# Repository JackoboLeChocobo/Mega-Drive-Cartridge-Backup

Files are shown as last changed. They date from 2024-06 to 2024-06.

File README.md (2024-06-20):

# Mega Drive Cartridge Backup

Fork du projet de X-Death25, auteur originel du projet : https://github.com/X-death25/MD-Dumper

Merci à lui pour les informations sur son projet et pour son aide sur l'utlisation du STM32F401CCU6.

## Objectifs

- Pouvoir récupérer les données de ses propres cartouches Mega Drive

## Outils utilisés

- Système d'exploitation : Debian 12 / Fenikkusu ( Linux )
- Carte de développement STM32F401CCU6 + 3x 74LS273

## Statut du projet 

En attente :

- Réalisation de la carte / Soudure

Etapes Validés :
- Schéma / Typon Kicad réalisés
- Firmware / Logiciel recompilables avec les outils open-source
- Programmeur du STM32F401CCU6 recompilable avec les outils open-source
- Détection du STM32F401CCU6 en tant que "Mega Drive Dumper" sous Linux avec dmesg et le logiciel d'utilisation
- Composants 74LS273 reçus

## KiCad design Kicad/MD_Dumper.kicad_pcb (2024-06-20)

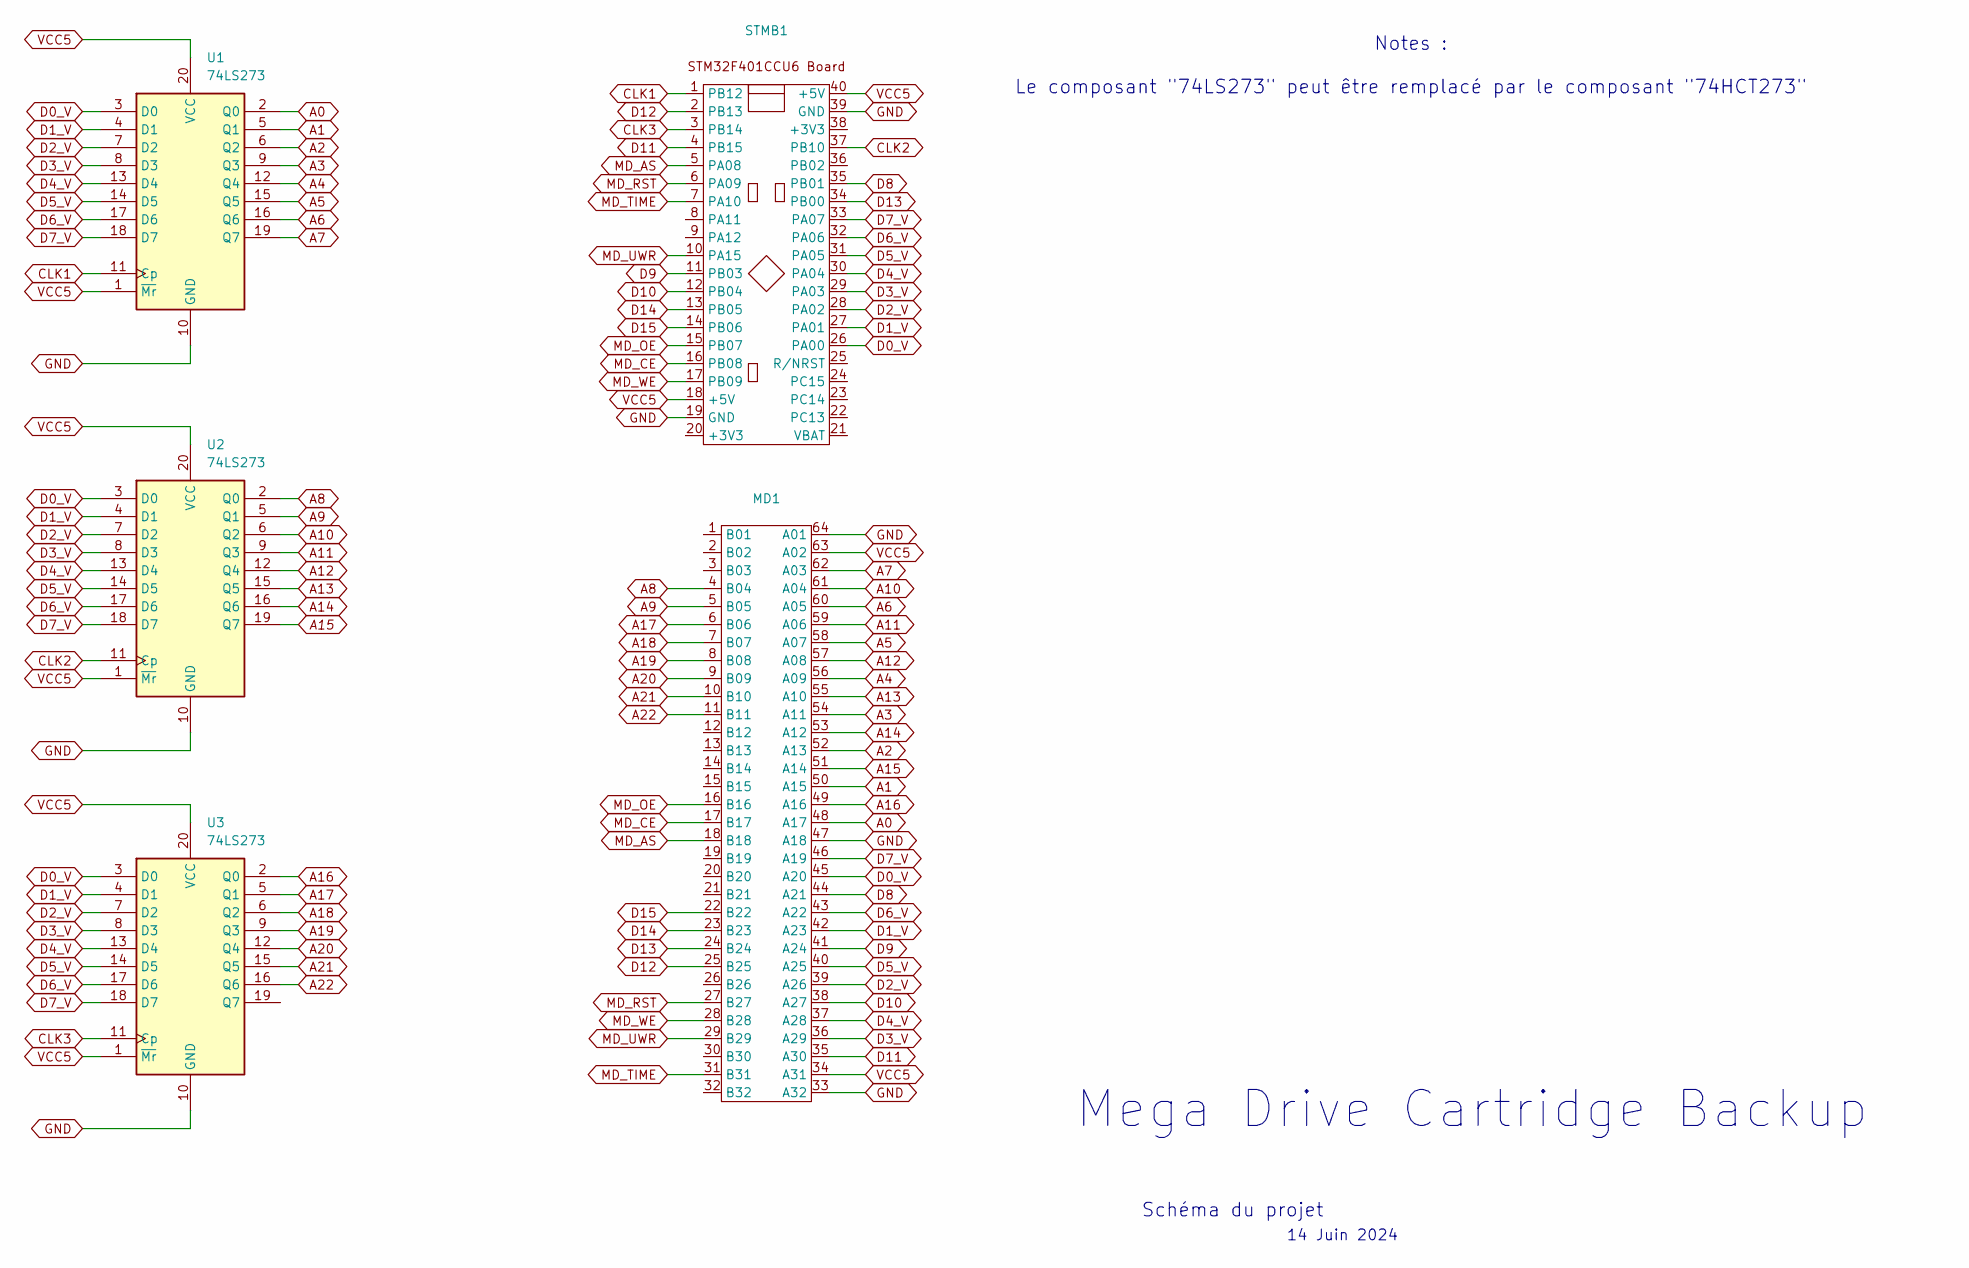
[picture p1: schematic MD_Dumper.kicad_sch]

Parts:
MD1: Conn_MD
STMB1: STM32F401CCU6 Board
U1, U2, U3: 74LS273; DIP-20_W7.62mm

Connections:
A0: MD1.48 (A17), U1.2 (Q0)
A1: MD1.50 (A15), U1.5 (Q1)
A2: MD1.52 (A13), U1.6 (Q2)
A3: MD1.54 (A11), U1.9 (Q3)
A4: MD1.56 (A09), U1.12 (Q4)
A5: MD1.58 (A07), U1.15 (Q5)
A6: MD1.60 (A05), U1.16 (Q6)
A7: MD1.62 (A03), U1.19 (Q7)
A8: MD1.4 (B04), U2.2 (Q0)
A9: MD1.5 (B05), U2.5 (Q1)
A10: MD1.61 (A04), U2.6 (Q2)
A11: MD1.59 (A06), U2.9 (Q3)
A12: MD1.57 (A08), U2.12 (Q4)
A13: MD1.55 (A10), U2.15 (Q5)
A14: MD1.53 (A12), U2.16 (Q6)
A15: MD1.51 (A14), U2.19 (Q7)
A16: MD1.49 (A16), U3.2 (Q0)
A17: MD1.6 (B06), U3.5 (Q1)
A18: MD1.7 (B07), U3.6 (Q2)
A19: MD1.8 (B08), U3.9 (Q3)
A20: MD1.9 (B09), U3.12 (Q4)
A21: MD1.10 (B10), U3.15 (Q5)
A22: MD1.11 (B11), U3.16 (Q6)
CLK1: STMB1.1 (PB12), U1.11 (Cp)
CLK2: STMB1.37 (PB10), U2.11 (Cp)
CLK3: STMB1.3 (PB14), U3.11 (Cp)
D0_V: MD1.45 (A20), STMB1.26 (PA00), U1.3 (D0), U2.3 (D0), U3.3 (D0)
D1_V: MD1.42 (A23), STMB1.27 (PA01), U1.4 (D1), U2.4 (D1), U3.4 (D1)
D2_V: MD1.39 (A26), STMB1.28 (PA02), U1.7 (D2), U2.7 (D2), U3.7 (D2)
D3_V: MD1.36 (A29), STMB1.29 (PA03), U1.8 (D3), U2.8 (D3), U3.8 (D3)
D4_V: MD1.37 (A28), STMB1.30 (PA04), U1.13 (D4), U2.13 (D4), U3.13 (D4)
D5_V: MD1.40 (A25), STMB1.31 (PA05), U1.14 (D5), U2.14 (D5), U3.14 (D5)
D6_V: MD1.43 (A22), STMB1.32 (PA06), U1.17 (D6), U2.17 (D6), U3.17 (D6)
D7_V: MD1.46 (A19), STMB1.33 (PA07), U1.18 (D7), U2.18 (D7), U3.18 (D7)
D8: MD1.44 (A21), STMB1.35 (PB01)
D9: MD1.41 (A24), STMB1.11 (PB03)
D10: MD1.38 (A27), STMB1.12 (PB04)
D11: MD1.35 (A30), STMB1.4 (PB15)
D12: MD1.25 (B25), STMB1.2 (PB13)
D13: MD1.24 (B24), STMB1.34 (PB00)
D14: MD1.23 (B23), STMB1.13 (PB05)
D15: MD1.22 (B22), STMB1.14 (PB06)
GND: MD1.33 (A32), MD1.47 (A18), MD1.64 (A01), STMB1.19 (GND), STMB1.39 (GND), U1.10 (GND), U2.10 (GND), U3.10 (GND)
MD_AS: MD1.18 (B18), STMB1.5 (PA08)
MD_CE: MD1.17 (B17), STMB1.16 (PB08)
MD_OE: MD1.16 (B16), STMB1.15 (PB07)
MD_RST: MD1.27 (B27), STMB1.6 (PA09)
MD_TIME: MD1.31 (B31), STMB1.7 (PA10)
MD_UWR: MD1.29 (B29), STMB1.10 (PA15)
MD_WE: MD1.28 (B28), STMB1.17 (PB09)
VCC5: MD1.34 (A31), MD1.63 (A02), STMB1.18 (+5V), STMB1.40 (+5V), U1.1 (~Mr), U1.20 (VCC), U2.1 (~Mr), U2.20 (VCC), U3.1 (~Mr), U3.20 (VCC)

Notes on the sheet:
Mega Drive Cartridge Backup
Notes : Le composant "74LS273" peut être remplacé par le composant "74HCT273"
14 Juin 2024
Schéma du projet

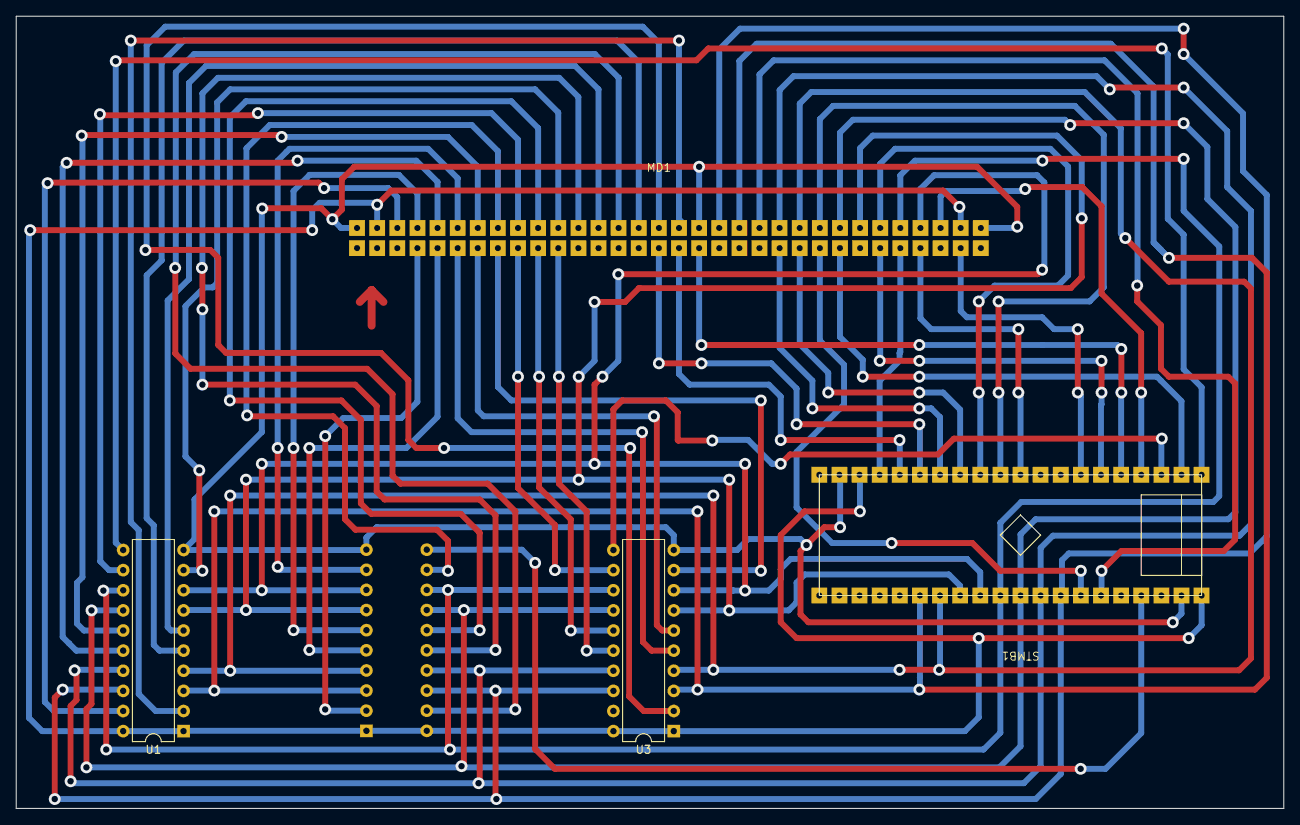
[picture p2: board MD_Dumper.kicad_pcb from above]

Board: 2 copper layers, 160.0 x 100.0 mm, 5 parts (1 on the bottom side), 51 nets.

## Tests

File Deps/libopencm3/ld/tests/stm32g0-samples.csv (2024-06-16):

# manually ripped from
# https://www.st.com/en/microcontrollers-microprocessors/stm32g0x0-value-line.html
# on 2024-01-17
name | flash | ram
stm32g030j6 | 32k | 8k
stm32g030f6 | 32k | 8k
stm32g030k6 | 32k | 8k
stm32g030c6 | 32k | 8k
stm32g050f6 | 32k | 18k
stm32g050k6 | 32k | 18k
stm32g050c6 | 32k | 18k
stm32g030k8 | 64k | 8k
stm32g030c8 | 64k | 8k
stm32g050k8 | 64k | 18k
stm32g050c8 | 64k | 18k
stm32g070kb | 128k | 36k
stm32g070cb | 128k | 36k
stm32g070rb | 128k | 36k
stm32g0b0ke | 512k | 144k
stm32g0b0ce | 512k | 144k
stm32g0b0re | 512k | 144k
stm32g0b0ve | 512k | 144k
# Ripped from https://www.st.com/en/microcontrollers-microprocessors/stm32g0x1.html
# on 2024-01-17
stm32g031j4 | 16k | 8k
stm32g031j6 | 32k | 8k
stm32g041j6 | 32k | 8k
stm32g031f4 | 16k | 8k
stm32g031f6 | 32k | 8k
stm32g041f6 | 32k | 8k
stm32g031g4 | 16k | 8k
stm32g031g6 | 32k | 8k
stm32g041g6 | 32k | 8k
stm32g031k4 | 16k | 8k
stm32g031k6 | 32k | 8k
stm32g041k6 | 32k | 8k
stm32g031c4 | 16k | 8k
stm32g031c6 | 32k | 8k
stm32g041c6 | 32k | 8k
stm32g051f6 | 32k | 18k
stm32g061f6 | 32k | 18k
stm32g051g6 | 32k | 18k
stm32g061g6 | 32k | 18k
stm32g051k6 | 32k | 18k
stm32g061k6 | 32k | 18k
stm32g051c6 | 32k | 18k
stm32g061c6 | 32k | 18k
stm32g031f8 | 64k | 8k
stm32g041f8 | 64k | 8k
stm32g051f8 | 64k | 18k
stm32g061f8 | 64k | 18k
stm32g031g8 | 64k | 8k
stm32g041g8 | 64k | 8k
stm32g051g8 | 64k | 18k
stm32g061g8 | 64k | 18k
stm32g031k8 | 64k | 8k
stm32g041k8 | 64k | 8k
stm32g051k8 | 64k | 18k
stm32g061k8 | 64k | 18k
stm32g031c8 | 64k | 8k
stm32g041c8 | 64k | 8k
stm32g051c8 | 64k | 18k
stm32g061c8 | 64k | 18k
stm32g031y8 | 64k | 8k
stm32g041y8 | 64k | 8k
stm32g051y8 | 64k | 18k
stm32g061y8 | 64k | 18k
stm32g071g8 | 64k | 36k
stm32g071k8 | 64k | 36k
stm32g071c8 | 64k | 36k
stm32g071r8 | 64k | 36k
stm32g071gb | 128k | 36k
stm32g081gb | 128k | 36k
stm32g071kb | 128k | 36k
stm32g081kb | 128k | 36k
stm32g071cb | 128k | 36k
stm32g081cb | 128k | 36k
stm32g071rb | 128k | 36k
stm32g081rb | 128k | 36k
stm32g071eb | 128k | 36k
stm32g081eb | 128k | 36k
stm32g0b1kb | 128k | 144k
stm32g0b1kc | 256k | 144k
stm32g0c1kc | 256k | 144k
stm32g0b1cb | 128k | 144k
stm32g0b1cc | 256k | 144k
stm32g0c1cc | 256k | 144k
stm32g0b1rb | 128k | 144k
stm32g0b1rc | 256k | 144k
stm32g0c1rc | 256k | 144k
stm32g0b1mb | 128k | 144k
stm32g0b1mc | 256k | 144k
stm32g0c1mc | 256k | 144k
stm32g0b1vb | 128k | 144k
stm32g0b1vc | 256k | 144k
stm32g0c1vc | 256k | 144k
stm32g0b1ke | 512k | 144k
stm32g0c1ke | 512k | 144k
stm32g0b1ce | 512k | 144k
stm32g0c1ce | 512k | 144k
stm32g0b1re | 512k | 144k
stm32g0c1re | 512k | 144k
stm32g0b1me | 512k | 144k
stm32g0c1me | 512k | 144k
stm32g0b1ve | 512k | 144k
stm32g0c1ve | 512k | 144k
stm32g0b1ne | 512k | 144k
stm32g0c1ne | 512k | 144k

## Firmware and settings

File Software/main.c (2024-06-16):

/*
MD Dumper Software

------------------------------------------------------
* Modifications by Jackobo Le Chocobo - 06/2024
* 
* Objective : Save Cartridge Datas to PC only
* 
* - Removed Write/Flash Cartridge Methods
* - Removed DMC Support
* 
*  
* Original author : X-death - V 2.0 03/2022
* - Upated Flash algo R/W
* - Add Extra Hardware Game Detection
* - Add Sega Lock-ON support
* - Add SSFII classic support
* - Add Pier Solar Support (only dump ROM )
* - Preliminary DMC support
------------------------------------------------------

*/

#include <stdio.h>
#include <stdlib.h>
#include <stdarg.h>
#include <string.h>
#include <ctype.h>
#include <time.h>
#include <math.h>

#include <libusb.h>
#include <assert.h>

#include "s2k.h"

// USB Special Command
#define WAKEUP          0x10  // WakeUP for first STM32 Communication
#define READ_MD         0x11
#define READ_MD_SAVE    0x12
#define READ_SMS   		0x16
#define INFOS_ID        0x18
#define DEBUG_MODE      0x19
#define MAPPER_SSF2     0x20
#define MAPPER_PS   	0x30
#define UNLOCK_PS     	0x31
#define SAVE_BUFFER    	0x41
#define SEND_BUFFER    	0x42
#define WRITE_LOCK_ON  	0x45

// Version
#define MAX_VERSION 	2
#define MIN_VERSION 	0

// Sega Dumper Specific Variable

char * game_rom = NULL;
char * game_name = NULL;
const char unk[] = {"unknown"};
const char * save_msg[] = {	"WRITE SMD save",  //0
                            "ERASE SMD save"
                          }; //1
const char * wheel[] = { "-","\\","|","/"}; //erase wheel

// Sega Dumper Specific Function

void pause(char const *message)
{
    int c;

    printf("%s", message);
    fflush(stdout);

    while ((c = getchar()) != '\n' && c != EOF)
    {
    }
}

int array_search(unsigned int find, const int * tab, int inc, int tab_size)
{
    int i=0;
    for(i=0; i<tab_size; (i+=inc))
    {
        if(tab[i] == find)
        {
#if defined(DEBUG)
            printf("\n tab:%X find:%X, i:%d, i/inc:%d", tab[i], find, i, (i/inc));
#endif
            return i;
        }
    }
    return -1; //nothing found
}


unsigned int trim(unsigned char * buf, unsigned char is_out)
{

    unsigned char i=0, j=0;
    unsigned char tmp[49] = {0}; //max
    unsigned char tmp2[49] = {0}; //max
    unsigned char next = 1;

    /*check ascii remove unwanted ones and transform upper to lowercase*/
    if(is_out)
    {
        while(i<48)
        {
            if(buf[i]<0x30 || buf[i]>0x7A || (buf[i]>0x29 && buf[i]<0x41) || (buf[i]>0x5A && buf[i]<0x61))
                buf[i] = 0x20; //remove shiiit
            if(buf[i]>0x40 && buf[i]<0x5B)
                buf[i] += 0x20; //to lower case A => a
            i++;
        }
        i=0;
    }

    while(i<48)
    {
        if(buf[i]!=0x20)
        {
            if(buf[i]==0x2F)
                buf[i] = '-';
            tmp[j]=buf[i];
            tmp2[j]=buf[i];
            next = 1;
            j++;
        }
        else
        {
            if(next)
            {
                tmp[j]=0x20;
                tmp2[j]='_';
                next = 0;
                j++;
            }
        }
        i++;
    }

    next=0;
    if(tmp2[0]=='_')
    {
        next=1;    //offset
    }
    if(tmp[(j-1)]==0x20)
    {
        tmp[(j-1)] = tmp2[(j-1)]='\0';
    }
    else
    {
        tmp[j] = tmp2[j]='\0';
    }

    if(is_out)  //+4 for extension
    {
        game_rom = (char *)malloc(j-next +4);
        memcpy((unsigned char *)game_rom, (unsigned char *)tmp2 +next, j-next); //stringed file
    }

    game_name = (char *)malloc(j-next);
    memcpy((unsigned char *)game_name, (unsigned char *)tmp +next, j-next); //trimmed
    return 0;
}

int main()
{

    // LibUSB Specific Var


    int res                      = 0;        /* return codes from libusb functions */
    libusb_device_handle* handle = 0;        /* handle for USB device */
    int kernelDriverDetached     = 0;        /* Set to 1 if kernel driver detached */
    int numBytes                 = 0;        /* Actual bytes transferred. */
    unsigned char usb_buffer_in[64] = {0};   /* 64 byte transfer buffer IN */
    unsigned char usb_buffer_out[64] = {0};  /* 64 byte transfer buffer OUT */
    unsigned long len            = 0;        /* Number of bytes transferred. */

    // Dumper Specific Var

    unsigned long i=0;
    unsigned long j=0;
    unsigned long address=0;
    unsigned long save_address = 0;
    unsigned char *buffer_rom = NULL;
    unsigned char *buffer_save = NULL;
    unsigned char buffer_8b[64];
    unsigned char *buffer_header = NULL;
    unsigned char buffer_system[16];
    unsigned char region[5];
    unsigned char odd=0;
    char *game_region = NULL;
    int choixMenu=0;
    int checksum_header = 0;
    unsigned char manufacturer_id=0;
    unsigned char chip_id=0;
    unsigned short rom_id=0;
    unsigned short flash_id=0;
    unsigned char flash_algo=0;
    unsigned char sms_bank=0;
    unsigned char bank=0;

    // File manipulation Specific Var

    FILE *myfile;
    unsigned char octetActuel=0;

    int game_size=0;
    unsigned long save_size1 = 0;
    unsigned long save_size2 = 0;
    unsigned long save_size = 0;

    // Debug Specific Var

    unsigned char DisplayDebug =0;
    unsigned char Control_Data =0;
    unsigned char Debug_Time =1;
    unsigned char Debug_Asel =1;
    unsigned char Debug_LWR =1;
    char DebugCommand[0];
    unsigned long DebugAddress = 0;
    unsigned long CurrentAddress = 0;
    unsigned short CurrentData = 0xF;
    unsigned char *BufferROM;
    unsigned char *BufferTemp;
    char dump_name[64];
    char empty_flash[512];
    char dump_flash[512];




// Extra Hardware Type

//*****************************************************
// Hardware TYPES
// 0 = No Mapper
// 1 = Sega Virtual Processor SVP Samsung DSP SSP1601
// 2 = Sega 315-5779 Mapper Super Street Fighter 2
// 3 = Sega Lock-on ( Sonic & Knuckles )
// 4 = Extended SSF2 Mapper ( Overdrive 2 / DOA )
// 5 = WaterMelon T-5740 Mapper Pier Solar
//*****************************************************


// Extra Hardware Lookup Table
// Format = {chksum, HardwareType | CartrdigeSize}
// chksum is located in ROM at 0x18E (0xC7)
// Type and Size are combined to conserve memory

    static const unsigned short HardwareID [] =
    {
        0x345D, 0x0102,  // Virtua Racing EUR
        0x95AB, 0x0102,  // Virtua Racing USA
        0x3B99, 0x0102,  // Virtua Racing JAP
        0xE41D, 0x0205,  // Super Street Fighter 2 EUR
        0xE017, 0x0205,  // Super Street Fighter 2 USA
        0xCE25, 0x0205,  // Super Street Fighter 2 JAP
        0xCF50, 0x0205,  // Super Street Fighter 2 USA + hack Stef & Pyron
        0xDFB3, 0x0302,  // Sonic & Knuckles
    };
    unsigned short Hardwaredata=0;
    unsigned char Hardwaretype;
    unsigned long Hardwaresize;



    // Main Program

    printf("\n");
    printf(" ---------------------------------\n");
    printf("    Sega Dumper USB2 Software     \n");
    printf(" ---------------------------------\n");

    printf("Init LibUSB... \n");

    /* Initialise libusb. */

    res = libusb_init(0);
    if (res != 0)
    {
        fprintf(stderr, "Error initialising libusb.\n");
        return 1;
    }

    printf("LibUSB Init Sucessfully ! \n");


    printf("Detecting MD Dumper... \n");

    /* Get the first device with the matching Vendor ID and Product ID. If
     * intending to allow multiple demo boards to be connected at once, you
     * will need to use libusb_get_device_list() instead. Refer to the libusb
     * documentation for details. */

    handle = libusb_open_device_with_vid_pid(0, 0x0483, 0x5740);

    if (!handle)
    {
        fprintf(stderr, "Unable to open device.\n");
        return 1;
    }

    /* Claim interface #0. */

    res = libusb_claim_interface(handle, 0);
    if (res != 0)
    {
        res = libusb_claim_interface(handle, 1);
        if (res != 0)
        {
            printf("Error claiming interface.\n");
            return 1;
        }
    }

// Clean Buffer
    for (i = 0; i < 64; i++)
    {
        usb_buffer_in[i]=0x00;
        usb_buffer_out[i]=0x00;
    }
    i=0;
    for (i = 0; i < 512; i++)
    {
        empty_flash[i]=0xFF;
        dump_flash[i]=0xFF;
    }


// At this step we can try to read the buffer first wake up Sega Dumper

    usb_buffer_out[0] = WAKEUP;// Affect request to  WakeUP Command

    libusb_bulk_transfer(handle, 0x01,usb_buffer_out, sizeof(usb_buffer_out), &numBytes, 0); // Send Packets to Sega Dumper

    libusb_bulk_transfer(handle, 0x82, usb_buffer_in, sizeof(usb_buffer_in), &numBytes, 0);
    /*
    	printf("\nDisplaying USB IN buffer\n\n");
       for (i = 0; i < 64; i++)
        {
            printf("%02X ",usb_buffer_in[i]);
    		j++;
    		if (j==16){printf("\n");j=0;}
        }
    */

    printf("\nMD Dumper %.*s",6, (char *)usb_buffer_in);
    printf("\n");
    printf("Hardware Firmware version : %d", usb_buffer_in[20]);
    printf(".%d\n", usb_buffer_in[21]);
    printf("Software Firmware version : %d",MAX_VERSION);
    printf(".%d\n",MIN_VERSION);

    // while(1);


// Now try to detect cartridge type ( SMS or MD )



    // First try to read ROM MD Header

    buffer_header = (unsigned char *)malloc(0x200);
    i = 0;
    address = 0x80;

    // Cleaning header Buffer
    for (i=0; i<512; i++)
    {
        buffer_header[i]=0x00;
    }

    i = 0;


    while (i<8)
    {

        usb_buffer_out[0] = READ_MD;
        usb_buffer_out[1] = address&0xFF ;
        usb_buffer_out[2] = (address&0xFF00)>>8;
        usb_buffer_out[3]=(address & 0xFF0000)>>16;
        usb_buffer_out[4] = 0; // Slow Mode

        libusb_bulk_transfer(handle, 0x01,usb_buffer_out, sizeof(usb_buffer_out), &numBytes, 60000);
        libusb_bulk_transfer(handle, 0x82,buffer_header+(64*i),64, &numBytes, 60000);
        address+=32;
        i++;
    }


    if(memcmp((unsigned char *)buffer_header,"SEGA",4) == 0)
    {
        printf("\nMegadrive/Genesis/32X cartridge detected!\n");

        for(i=0; i<(256/16); i++)
        {
            printf("\n");
            printf(" %03lX", 0x100+(i*16));
            for(j=0; j<16; j++)
            {
                printf(" %02X", buffer_header[j+(i*16)]);
            }
            printf(" %.*s", 16, buffer_header +(i*16));
        }

        printf("\n");
        printf("\n --- HEADER ---\n");
        memcpy((unsigned char *)dump_name, (unsigned char *)buffer_header+32, 48);
        trim((unsigned char *)dump_name, 0);
        printf(" Domestic: %.*s\n", 48, (char *)game_name);
        memcpy((unsigned char *)dump_name, (unsigned char *)buffer_header+80, 48);
        trim((unsigned char *)dump_name, 0);

        printf(" International: %.*s\n", 48, game_name);
        printf(" Release date: %.*s\n", 16, buffer_header+0x10);
        printf(" Version: %.*s\n", 14, buffer_header+0x80);
        memcpy((unsigned char *)region, (unsigned char *)buffer_header +0xF0, 4);
        for(i=0; i<4; i++)
        {
            if(region[i]==0x20)
            {
                game_region = (char *)malloc(i);
                memcpy((unsigned char *)game_region, (unsigned char *)buffer_header +0xF0, i);
                game_region[i] = '\0';
                break;
            }
        }

        if(game_region[0]=='0')
        {
            game_region = (char *)malloc(4);
            memcpy((char *)game_region, (char *)unk, 3);
            game_region[3] = '\0';
        }

        printf(" Region: %s\n", game_region);

        checksum_header = (buffer_header[0x8E]<<8) | buffer_header[0x8F];
        printf(" Checksum: %X\n", checksum_header);

        game_size = 1 + ((buffer_header[0xA4]<<24) | (buffer_header[0xA5]<<16) | (buffer_header[0xA6]<<8) | buffer_header[0xA7])/1024;
        printf(" Game size: %dKB\n", game_size);



        if((buffer_header[0xB0] + buffer_header[0xB1])!=0x93)
        {
            printf(" Extra Memory : No\n");
        }
        else
        {
            printf(" Extra Memory : Yes ");
            switch(buffer_header[0xB2])
            {
            case 0xF0:
                printf(" 8bit backup SRAM (even addressing)\n");
                break;
            case 0xF8:
                printf(" 8bit backup SRAM (odd addressing)\n");
                break;
            case 0xB8:
                printf(" 8bit volatile SRAM (odd addressing)\n");
                break;
            case 0xB0:
                printf(" 8bit volatile SRAM (even addressing)\n");
                break;
            case 0xE0:
                printf(" 16bit backup SRAM\n");
                break;
            case 0xA0:
                printf(" 16bit volatile SRAM\n");
                break;
            case 0xE8:
                printf(" Serial EEPROM\n");
                break;
            }
            if ( buffer_header[0xB2] != 0xE0 | buffer_header[0xB2] != 0xA0 ) // 8 bit SRAM
            {
                save_size2 = (buffer_header[0xB8]<<24) | (buffer_header[0xB9]<<16) | (buffer_header[0xBA] << 8) | buffer_header[0xBB];
                save_size1 = (buffer_header[0xB4]<<24) | (buffer_header[0xB5]<<16) | (buffer_header[0xB6] << 8) | buffer_header[0xB7];

                save_size = save_size2 - save_size1;
                save_size = (save_size/1024); // Kb format
                save_size=(save_size/2) + 1; // 8bit size
            }
            save_address = (buffer_header[0xB4]<<24) | (buffer_header[0xB5]<<16) | (buffer_header[0xB6] << 8) | buffer_header[0xB7];
            printf(" Save size: %dKb\n", save_size);
            printf(" Save address: %lX\n", save_address);

            if(usb_buffer_in[0xB2]==0xE8) // EEPROM Game
            {
                printf(" No information on this game!\n");
            }
        }
    }


    // Extra Hardware detection Specific code

    // Search checksum cartridge in Custom Hardware game table

    for (i = 0; i < sizeof(HardwareID)/sizeof(short); i++)
    {
        if ( checksum_header == HardwareID[i] )
        {
            Hardwaredata=HardwareID[i+1];
            Hardwaretype = Hardwaredata >> 8;
            Hardwaresize = Hardwaredata & 0x0F;

            if ( Hardwaredata == 0x0302)
            {
                printf(" Extra Hardware : Sega Lock-ON \n");
                game_size=1024*Hardwaresize*1024;
                Hardwaretype = 3;
            }
            if ( Hardwaredata == 0x0205)
            {
                printf(" Extra Hardware : Sega 315-5779 Mapper Super Street Fighter 2 \n");
                game_size=1024*Hardwaresize*1024;
            }
        }
    }
    // Overdrive 2 detection support : https://plutiedev.com/beyond-4mb
    if(memcmp((unsigned char *)buffer_system,"SEGA SSF",8) == 0)
    {
        printf(" Extra Hardware : Extended Sega SSF2 mapper \n");
        game_size=1024*8192;
        Hardwaretype = 4;
    }

    // Pier Solar detection support
    if(memcmp((unsigned char *)dump_name,"PIER SOLAR",10) == 0)
    {
        printf(" Extra Hardware : WaterMelon T-5740 Mapper Pier Solar \n");
        game_size=1024*8192;
        Hardwaretype = 5;
    }

    /*else   // Try to read in SMS mode
    {

    	address = 0x7FF0;
    	usb_buffer_out[0] = READ_SMS;
    	usb_buffer_out[1] = address&0xFF ;
        usb_buffer_out[2] = (address&0xFF00)>>8;
        usb_buffer_out[3]=(address & 0xFF0000)>>16;
        usb_buffer_out[4] = 0; // Slow Mode

        libusb_bulk_transfer(handle, 0x01,usb_buffer_out, sizeof(usb_buffer_out), &numBytes, 0);
    	libusb_bulk_transfer(handle, 0x82, usb_buffer_in, sizeof(usb_buffer_in), &numBytes, 0);



    	if(memcmp((unsigned char *)usb_buffer_in,"TMR SEGA",8) == 0)
    		{
    			printf("\nMaster System/Mark3 cartridge detected !\n");
    			printf("Region : ");
    			if ( usb_buffer_in[15] >> 6 == 0x01 ){ printf("USA / EUR\n");}
    			if ( usb_buffer_in[15] >> 4 == 0x03 ){ printf("Japan\n");}
    			if ( usb_buffer_in[15] >> 4 == 0x03 ){ printf("Japan\n");}
    			game_size = usb_buffer_in[15] & 0xF;
    			//printf("Game Size : %ld Ko \n",game_size);
    			if (game_size == 0x00){ printf("Game Size : 256 Ko");game_size = 256*1024;}
    			if (game_size == 0x01){ printf("Game Size : 512 Ko");game_size = 512*1024;}
    			if (game_size == 0x0c){ printf("Game Size : 32 Ko");game_size = 32*1024;}
    			if (game_size == 0x0e){ printf("Game Size : 64 Ko");game_size = 64*1024;}
    			if (game_size == 0x0f){ printf("Game Size : 128 Ko");game_size = 128*1024;}

    		}*/

    /* 	else
     		{
     			printf(" \nUnknown cartridge type\n(erased flash eprom or bad connection,...)\n");
     		}
    */
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
